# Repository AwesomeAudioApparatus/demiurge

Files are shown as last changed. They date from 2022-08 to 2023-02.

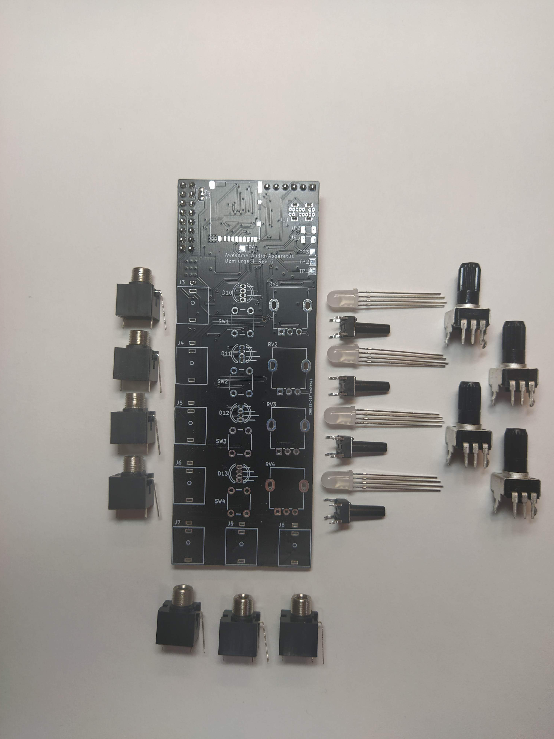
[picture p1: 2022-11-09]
photos/demiurge1-RevG-14.jpg

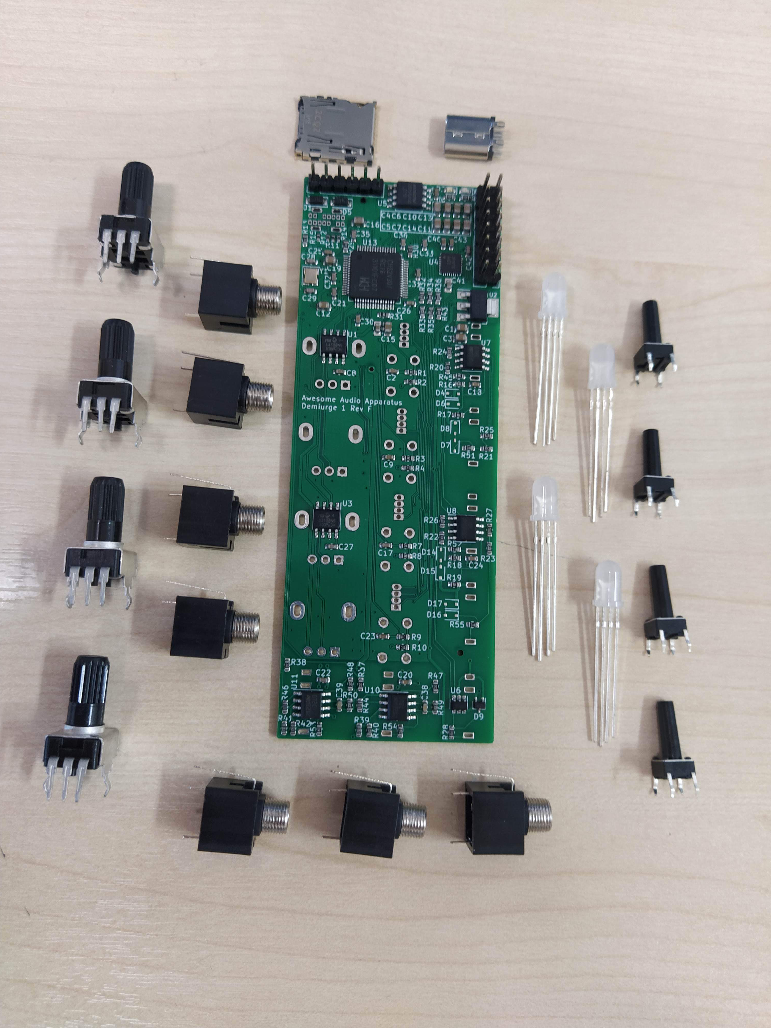
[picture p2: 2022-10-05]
photos/demiurge1-kit-2.jpg

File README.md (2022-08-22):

# Demiurge

Demiurge is a combination of Hardware and Software for Digital Sound Processing in the Eurorack Modular Synthesizer environment.

The "Demiurge 1" board is an 8 HP Eurorack compatible board, the functionality defined in software and custom front panel can either 
be made by hand, ordered from local mechanical shops or ordered from PCB manufacturers (KiCad template for front panel exists).

The "Demiurge Sound Processing Engine" is a system to more easily create Eurorack module functionality. A simple VCO module may look like this;

```C
#include "demiurge.h"
#include "demiurge-board.h"

static control_pair_t pair1;  // frequency
static control_pair_t pair2;  // amplitude

static control_pair_t pair3;  // frequency
static control_pair_t pair4;  // amplitude

static audio_outport_t out1;
static audio_outport_t out2;
static oscillator_t oscillator1;
static oscillator_t oscillator2;

/* Simple 2 VCO. SAW on output 1 and SQUARE on output 2. */

void vco_prepare() {
    demiurge_samplerate = 48000;      // 48000 samples/second
    demiurge_set_inport_cv(1);
    demiurge_set_inport_cv(2);
    demiurge_set_inport_cv(3);
    demiurge_set_inport_cv(4);

    demiurge_set_outport_audio(1);
    demiurge_set_outport_audio(2);
}

void vco_setup() {
    // Initialize the hardware configuration
    control_pair_init(&pair1, 1);     // FREQUENCY = CV+Pot at the top
    control_pair_init(&pair2, 2);     // AMPLITUDE = CV+Pot at the second position from the top
    control_pair_init(&pair3, 3);     // FREQUENCY = CV+Pot at the third position from top
    control_pair_init(&pair4, 4);     // AMPLITUDE = CV+Pot at the bottom
    audio_outport_init(&out1, 1);     // Audio Out on left output channel
    audio_outport_init(&out2, 2);     // Audio Out on right output channel

    // Initialize the oscillators
    oscillator_init(&oscillator1);
    oscillator_init(&oscillator2);

    // Set up the oscillators to SINE wave form

    oscillator_configure_mode(&oscillator1, SAW);
    oscillator_configure_mode(&oscillator2, SQUARE);

    oscillator_configure_frequency(&oscillator1, &pair1.me);
    oscillator_configure_frequency(&oscillator2, &pair3.me);

    oscillator_configure_amplitude(&oscillator1, &pair2.me);
    oscillator_configure_amplitude(&oscillator2, &pair4.me);

    // Connect Oscillator to outputs
    audio_outport_configure_input(&out1, &oscillator1.me);
    audio_outport_configure_input(&out2, &oscillator2.me);
}

void vco_loop() {
   // handle buttons and LEDs
}

int main(void)
{
    vco_prepare();                  // Prepare the board for the functionality

    demiurge_driver_init();         // Initialize the hardware driver
    demiurge_init();                // Initialize the Demiurge platform
    vco_setup();                    // Set up the functionality
    demiurge_start();               // Start the audio processing
    while(1)
    {
        vco_loop();                 // Give time for LEDs and Buttons
    }
}

```

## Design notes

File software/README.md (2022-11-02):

# Readme
This software is organized to be a Demiurge Sound Processing project, from
which the STM32PackCreator (../stm32-packs/demiurge1) will read the files to
package up the installable Software Pack in STM32CubeMX.

**NOTE 1**: This is intended as the development environment for the Installable 
packs, not to derive your own projects from.

**NOTE 2**: Only the build system and IDE setup of Jetbrains' CLion IDE will
be actively maintained. Any STM32CubeIDE files may or may not work; maintainers
are welcome.

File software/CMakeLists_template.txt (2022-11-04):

#${templateWarning}
set(CMAKE_SYSTEM_NAME Generic)
set(CMAKE_SYSTEM_VERSION 1)
${cmakeRequiredVersion}

if ("$${CMAKE_BUILD_TYPE}" STREQUAL "")
    set(CMAKE_BUILD_TYPE Debug)
endif()

# project settings
project(${projectName} C ASM)
set(CMAKE_C_STANDARD 11)

# specify cross-compilers and tools
set(CMAKE_C_COMPILER arm-none-eabi-gcc)
set(CMAKE_ASM_COMPILER arm-none-eabi-gcc)
set(CMAKE_AR arm-none-eabi-ar)
set(CMAKE_OBJCOPY arm-none-eabi-objcopy)
set(CMAKE_OBJDUMP arm-none-eabi-objdump)
set(SIZE arm-none-eabi-size)
set(CMAKE_TRY_COMPILE_TARGET_TYPE STATIC_LIBRARY)

add_compile_definitions(ARM_MATH_CM4;ARM_MATH_MATRIX_CHECK;ARM_MATH_ROUNDING)
add_compile_options(-mfloat-abi=hard -mfpu=fpv4-sp-d16)
add_link_options(-mfloat-abi=hard -mfpu=fpv4-sp-d16)

add_compile_options(-mcpu=${mcpu} -mthumb -mthumb-interwork)
add_compile_options(-ffunction-sections -fdata-sections -fno-common -fmessage-length=0)

# Enable assembler files preprocessing
add_compile_options($<$<COMPILE_LANGUAGE:ASM>:-x$<SEMICOLON>assembler-with-cpp>)

add_definitions(-DSTM32F446xx -DUSE_HAL_DRIVER -DARM_MATH_CM4 -DDEBUG)

set(LINKER_SCRIPT ${CMAKE_SOURCE_DIR}/STM32F446RETX_FLASH.ld)

add_link_options(-mcpu=cortex-m4 -mthumb -mthumb-interwork)
add_link_options(-Wl,-gc-sections,--print-memory-usage,-Map=${PROJECT_BINARY_DIR}/${PROJECT_NAME}-stm32f446.map)
add_link_options(-T ${LINKER_SCRIPT})

if ("$${CMAKE_BUILD_TYPE}" STREQUAL "Release")
    message(STATUS "Maximum optimization for speed")
    add_compile_options(-Ofast)
elseif ("$${CMAKE_BUILD_TYPE}" STREQUAL "RelWithDebInfo")
    message(STATUS "Maximum optimization for speed, debug info included")
    add_compile_options(-Ofast -g)
elseif ("$${CMAKE_BUILD_TYPE}" STREQUAL "MinSizeRel")
    message(STATUS "Maximum optimization for size")
    add_compile_options(-Os)
else ()
    message(STATUS "Minimal optimization, debug info included")
    add_compile_options(-Og -g)
endif ()

include_directories(${includes})

include_directories(
        Drivers/BSP/AwesomeAudioApparatus_board/Demiurge1
        Middlewares/ThirdParty/AwesomeAudioApparatus_Audio/Demiurge/inc
        User/
        Middlewares/ST/ARM/DSP/Inc
)

add_definitions(${defines})

file(GLOB_RECURSE SOURCES ${sources} "Middlewares/*.*" "User/App/*.*" "Drivers/*.*")

set(LINKER_SCRIPT $${CMAKE_SOURCE_DIR}/${linkerScript})

add_link_options(-Wl,-gc-sections,--print-memory-usage,-Map=$${PROJECT_BINARY_DIR}/$${PROJECT_NAME}.map)
add_link_options(-mcpu=${mcpu} -mthumb -mthumb-interwork)
add_link_options(-T $${LINKER_SCRIPT})

link_libraries(m)
add_executable($${PROJECT_NAME}.elf $${SOURCES} $${LINKER_SCRIPT})
target_link_libraries(${PROJECT_NAME}.elf ${CMAKE_SOURCE_DIR}/Middlewares/ST/ARM/DSP/Lib/libarm_cortexM4l_math.a)

set(HEX_FILE $${PROJECT_BINARY_DIR}/$${PROJECT_NAME}.hex)
set(BIN_FILE $${PROJECT_BINARY_DIR}/$${PROJECT_NAME}.bin)

add_custom_command(TARGET $${PROJECT_NAME}.elf POST_BUILD
        COMMAND $${CMAKE_OBJCOPY} -Oihex $<TARGET_FILE:$${PROJECT_NAME}.elf> $${HEX_FILE}
        COMMAND $${CMAKE_OBJCOPY} -Obinary $<TARGET_FILE:$${PROJECT_NAME}.elf> $${BIN_FILE}
        COMMENT "Building $${HEX_FILE}
Building $${BIN_FILE}")

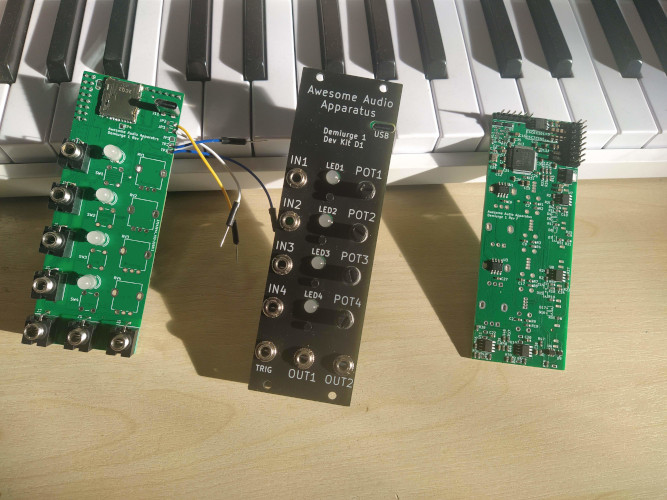
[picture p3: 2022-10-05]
photos/opencart/demiurge1-RevF-8-opencart.jpg

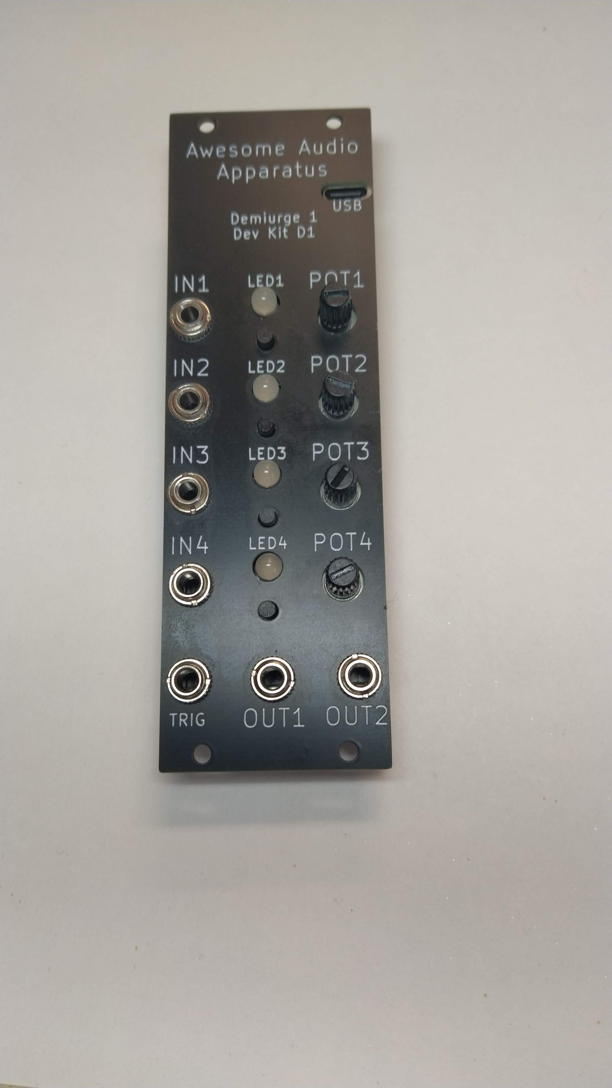
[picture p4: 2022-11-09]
photos/demiurge1-RevG-10.jpg

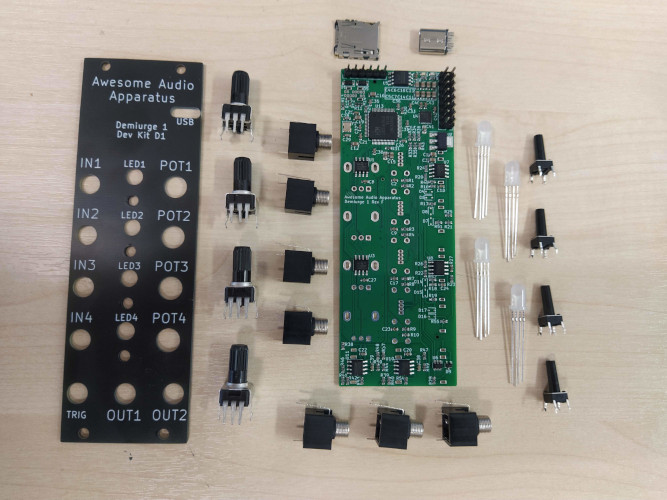
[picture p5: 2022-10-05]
photos/opencart/demiurge1-kit-1-opencart.jpg

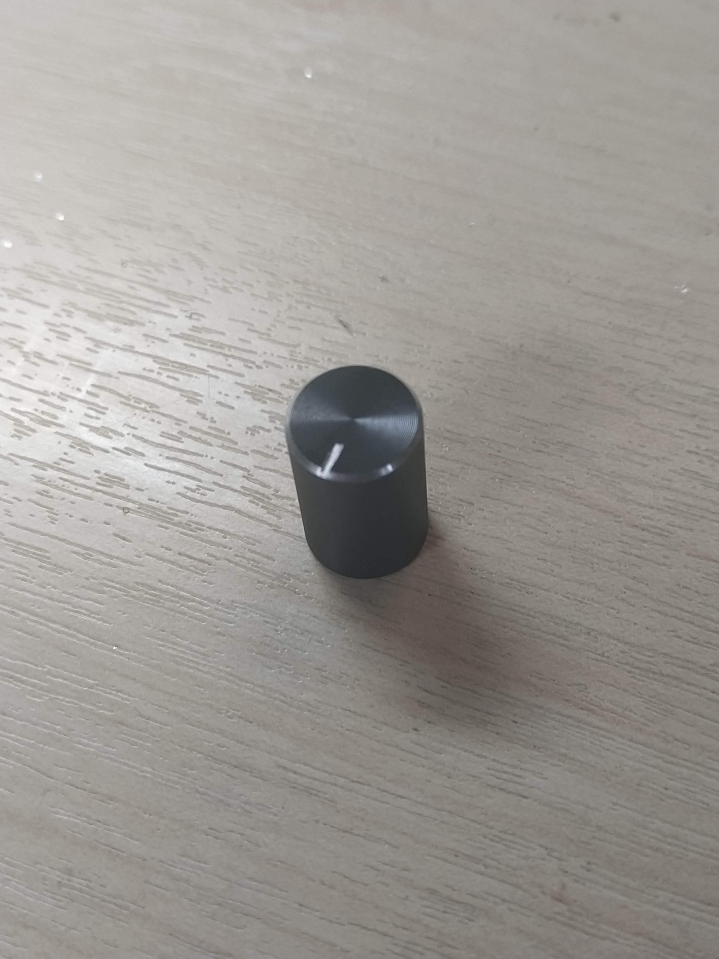
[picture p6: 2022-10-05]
photos/knob-4.jpg

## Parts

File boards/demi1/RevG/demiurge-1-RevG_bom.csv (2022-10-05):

Comment | Designator | Footprint | LCSC
22uF | C1,C3,C4,C5,C6,C7,C10,C11,C12,C13,C14,C15,C16,C19 | Capacitor_SMD:C_0805_2012Metric | C129303
100nF | C2,C8,C9,C17,C18,C20,C21,C22,C23,C24,C25,C26,C27,C30,C31,C32,C33,C34,C35,C36,C42,C43 | Capacitor_SMD:C_0603_1608Metric | C14663
20pF | C28,C29 | Capacitor_SMD:C_0603_1608Metric | C1648
4.7uF | C37,C41 | Capacitor_SMD:C_0805_2012Metric | C19666
1nF | C38,C39 | Capacitor_SMD:C_0603_1608Metric | C1588
1uF | C40 | Capacitor_SMD:C_0603_1608Metric | C15849
~ | D1,D5 | Diode_SMD:D_SOD-123 | C8598
~ | D10,D11,D12,D13 | LED_THT:LED_D5.0mm-4_RGB | C331057
Red | D2 | LED_SMD:LED_0603_1608Metric | C2286
Green | D3 | LED_SMD:LED_0603_1608Metric | C72043
10V | D4,D6,D7,D8,D14,D15,D16,D17 | Diode_SMD:D_SOD-323 | C493185
BAT54SW | D9 | Package_TO_SOT_SMD:SOT-323_SC-70 | C78260
~ | J1 | Connector_PinHeader_2.54mm:PinHeader_2x08_P2.54mm_Vertical | C68234
~ | J11 | aaa:USB_C_Receptacle_Vertical | C167321
Micro_SD_Card_Det_Hirose_DM3AT | J12 | Connector_Card:microSD_HC_Hirose_DM3AT-SF-PEJM5 | C114218
Conn_01x06 | J2 | Connector_PinHeader_2.54mm:PinHeader_1x06_P2.54mm_Vertical | C37208
~ | J3,J4,J5,J6,J7,J8,J9 | aaa:PJ301M-12
~ | JP1 | Jumper:SolderJumper-3_P1.3mm_Bridged12_RoundedPad1.0x1.5mm
~ | JP2,JP3 | Capacitor_SMD:C_1206_3216Metric
10k | R1,R2,R3,R4,R7,R8,R9,R10,R13,R29,R37,R38,R47,R48 | Resistor_SMD:R_0603_1608Metric | C25804
22R | R11,R12 | Resistor_SMD:R_0402_1005Metric | C25092
5.1k | R14,R15 | Resistor_SMD:R_0402_1005Metric | C25905
18k | R16,R18 | Resistor_SMD:R_0603_1608Metric | C25810
13k | R17,R19 | Resistor_SMD:R_0603_1608Metric | C22797
20k | R20,R21,R22,R23,R49,R50 | Resistor_SMD:R_0603_1608Metric | C4184
3k3 | R24,R25,R26,R27,R56,R57 | Resistor_SMD:R_0603_1608Metric | C22978
1k | R28 | Resistor_SMD:R_0603_1608Metric | C21190
0R | R30,R31 | Capacitor_SMD:C_0603_1608Metric | C21189
51R | R32,R35 | Resistor_SMD:R_0603_1608Metric | C23197
20R | R33,R34,R36,R43 | Resistor_SMD:R_0603_1608Metric | C22950
36k | R39,R41 | Resistor_SMD:R_0603_1608Metric | C23147
22k | R40,R42 | Resistor_SMD:R_0603_1608Metric | C31850
33k | R44,R46 | Resistor_SMD:R_0603_1608Metric | C4216
100 | R45,R51,R52,R53,R54,R55 | Resistor_SMD:R_0603_1608Metric | C22775
2k | R5,R6 | Resistor_SMD:R_0603_1608Metric | C22975
~ | RV1,RV2,RV3,RV4 | aaa:Potentiometer_Alpha_RD901F-40-00D_Single_Vertical
~ | SW1,SW2,SW3,SW4 | Button_Switch_THT:SW_PUSH_6mm_H8mm
TP1 | TP1 | TestPoint:TestPoint_Pad_1.5x1.5mm
TP2 | TP2 | TestPoint:TestPoint_Pad_1.5x1.5mm
SWO | TP3,TP4 | TestPoint:TestPoint_Pad_1.5x1.5mm
MCP6002 | U1,U3 | Package_SO:SOIC-8_3.9x4.9mm_P1.27mm | C7377
STM32F446 | U13 | Package_QFP:LQFP-64_10x10mm_P0.5mm | C69336
AMS1117-3.3 | U2 | Package_TO_SOT_SMD:SOT-223-3_TabPin2 | C6186
AW20036 | U4 | Package_DFN_QFN:QFN-32-1EP_4x4mm_P0.4mm_EP2.65x2.65mm_ThermalVias | C401019
W25Q128JVS | U5 | Package_SO:SOIC-8_5.23x5.23mm_P1.27mm | C97521
74LVC1T45W6 | U6 | Package_TO_SOT_SMD:SOT-23-6 | C7843
TL072 | U7,U8,U10,U11 | Package_SO:SOIC-8_3.9x4.9mm_P1.27mm | C6961
16MHz | Y1 | Crystal:Crystal_SMD_3225-4Pin_3.2x2.5mm | C13738

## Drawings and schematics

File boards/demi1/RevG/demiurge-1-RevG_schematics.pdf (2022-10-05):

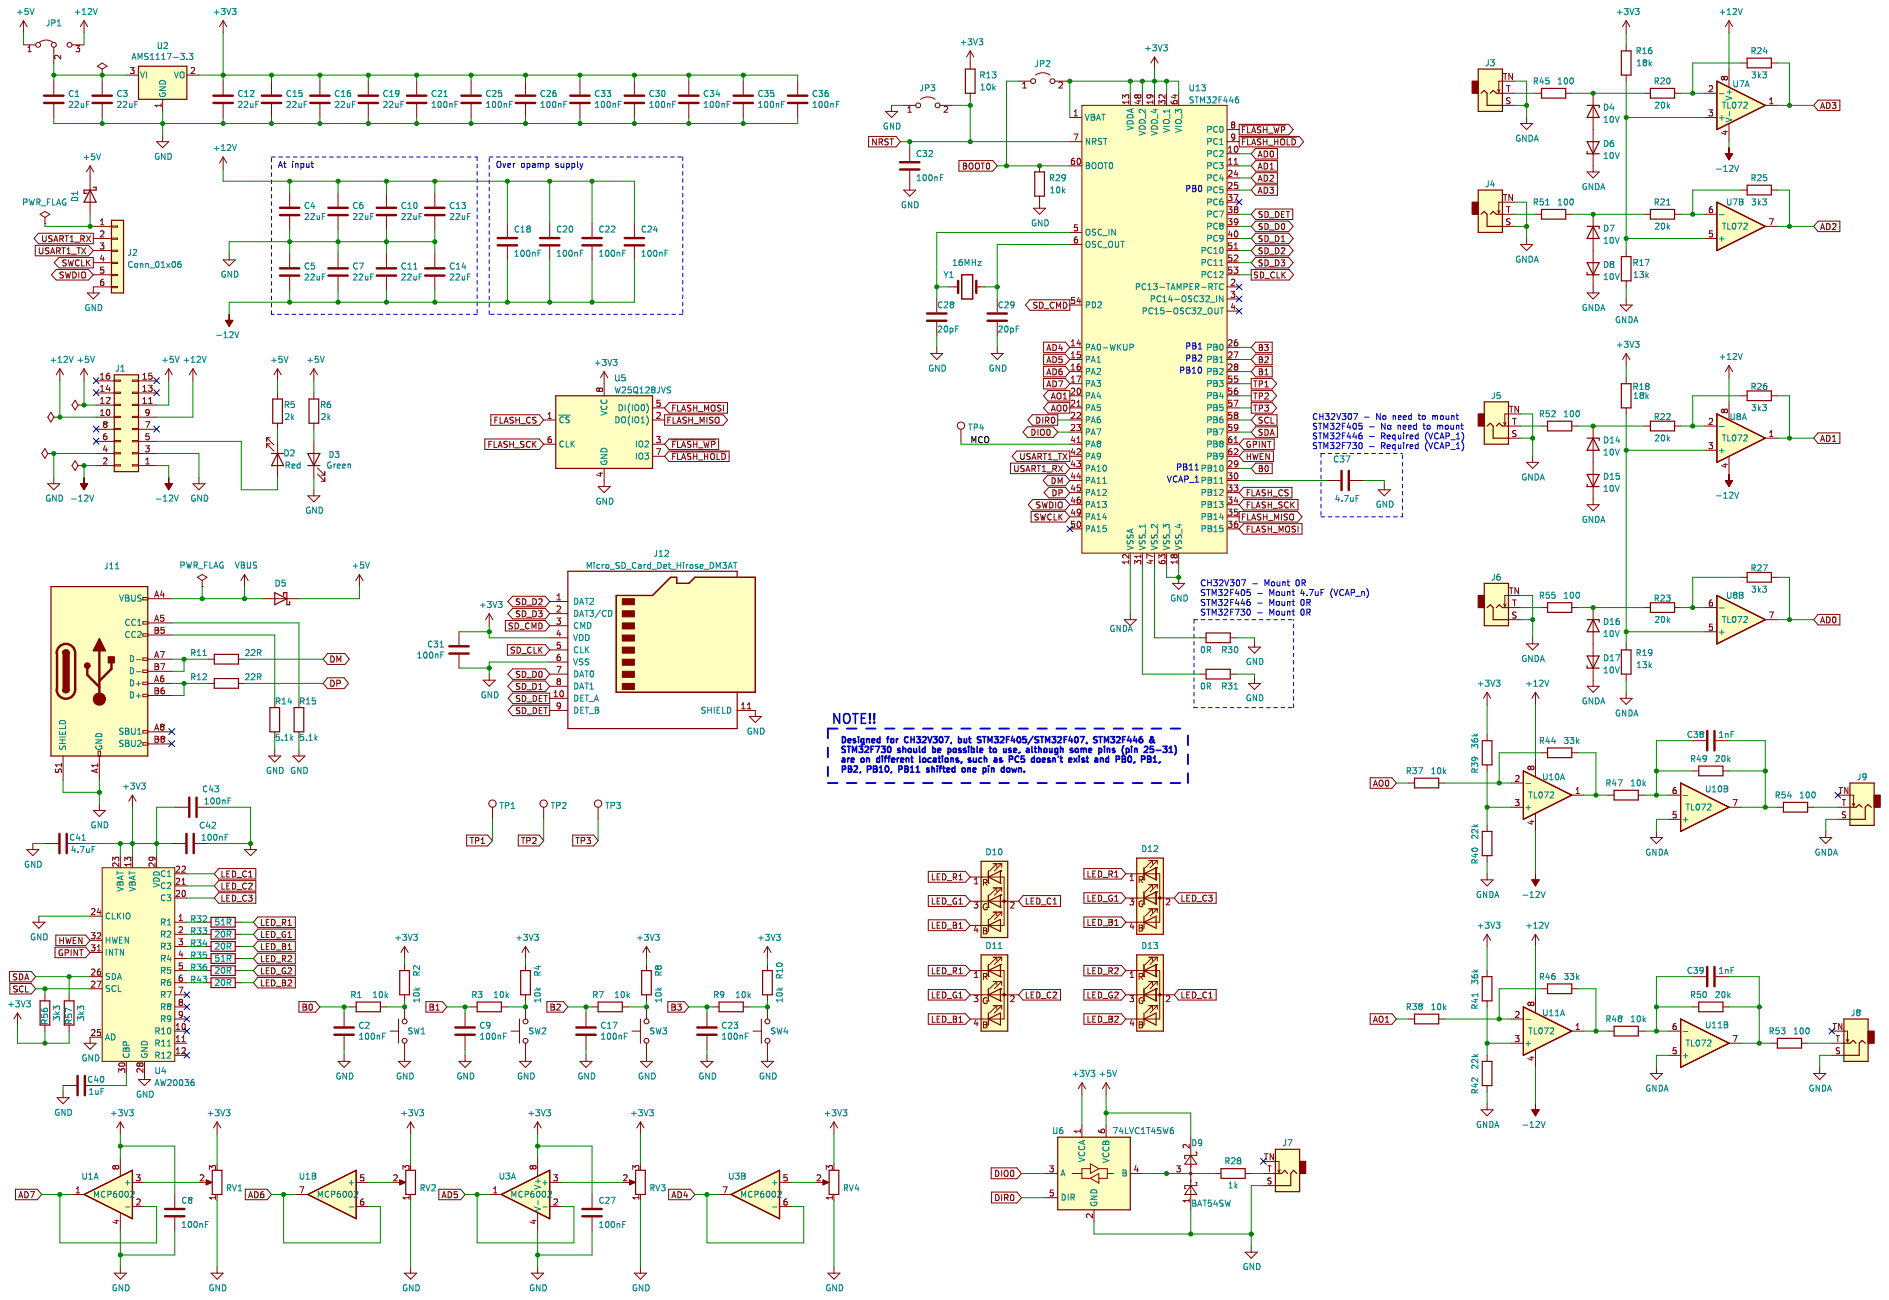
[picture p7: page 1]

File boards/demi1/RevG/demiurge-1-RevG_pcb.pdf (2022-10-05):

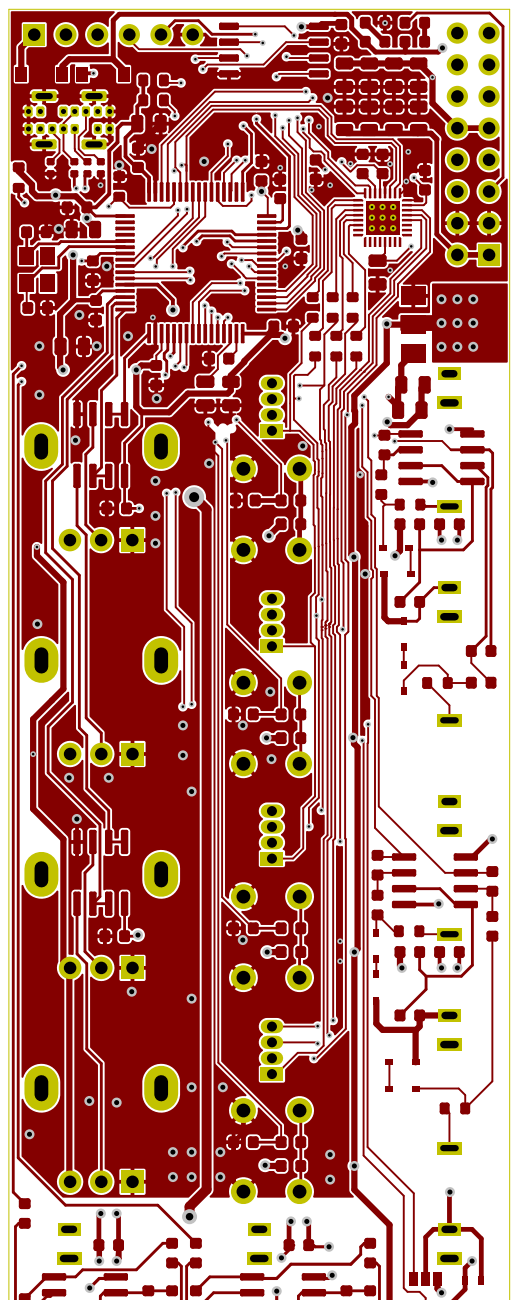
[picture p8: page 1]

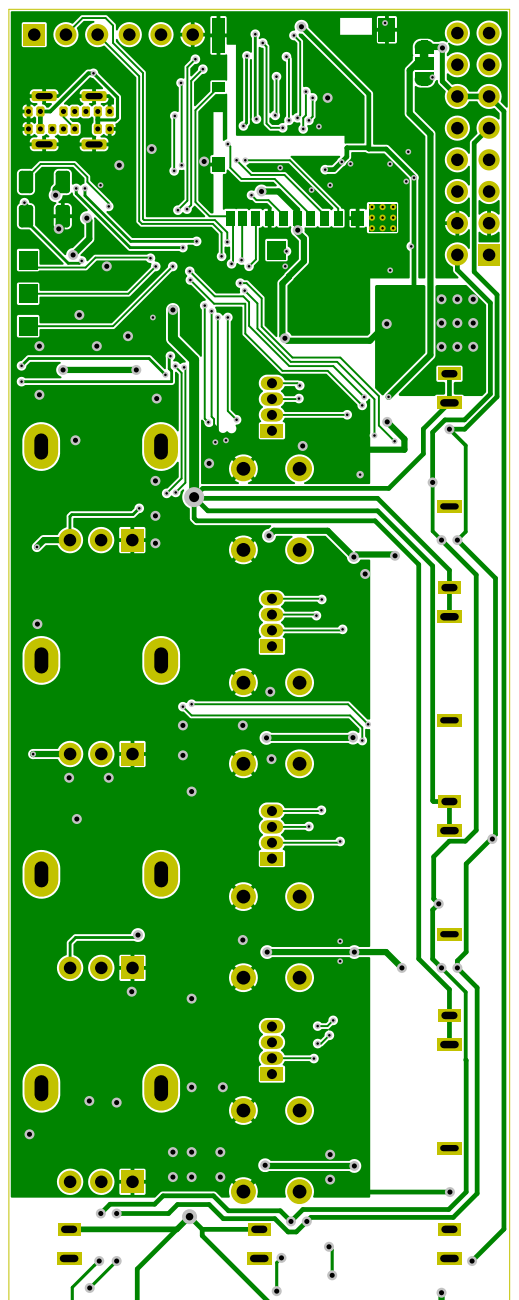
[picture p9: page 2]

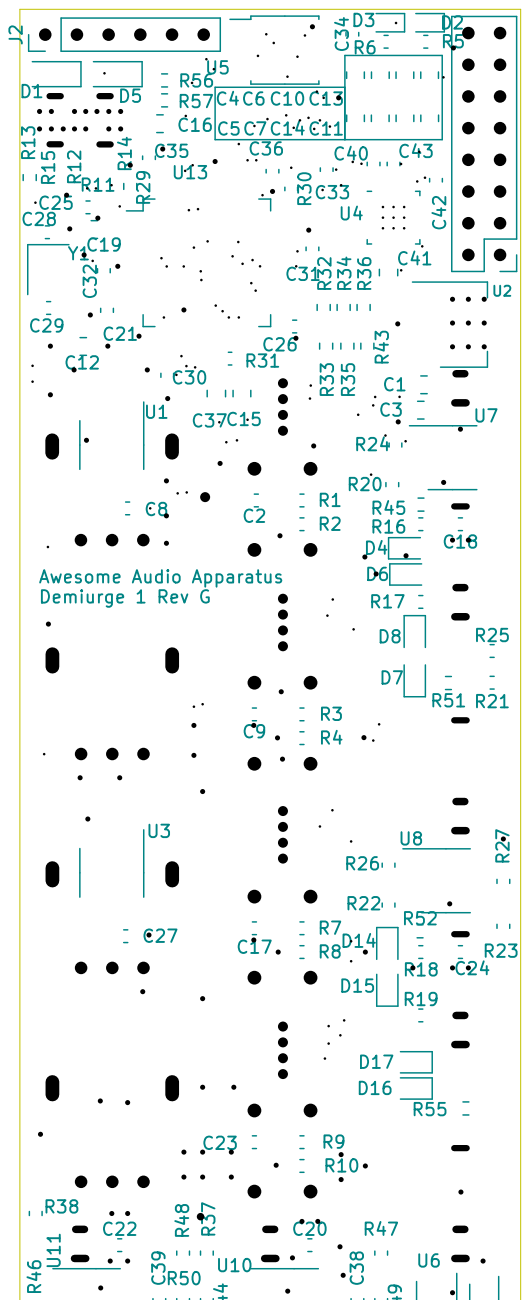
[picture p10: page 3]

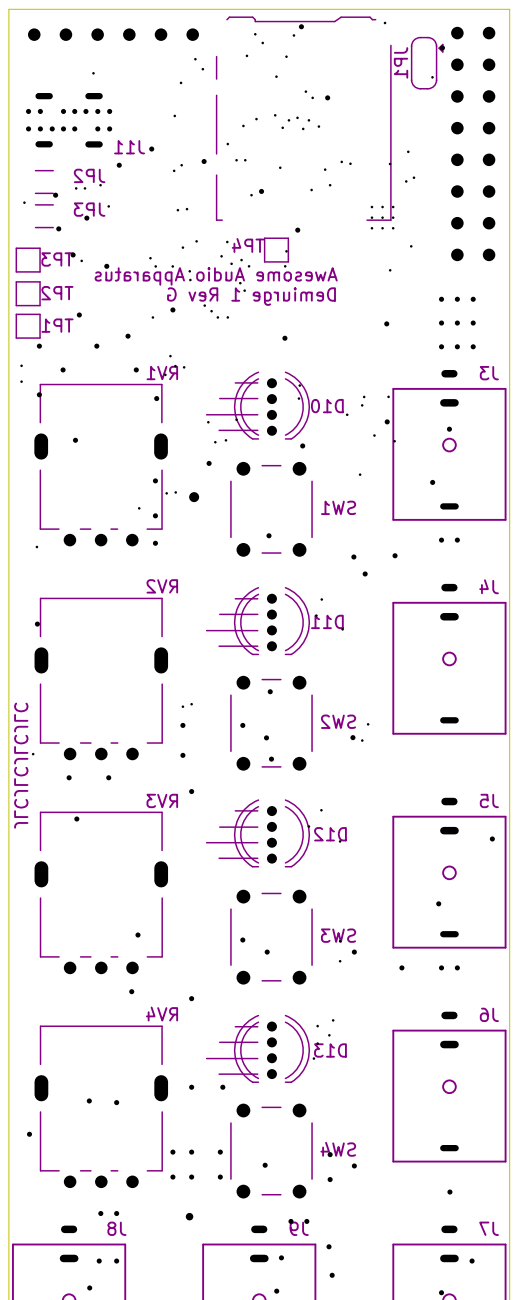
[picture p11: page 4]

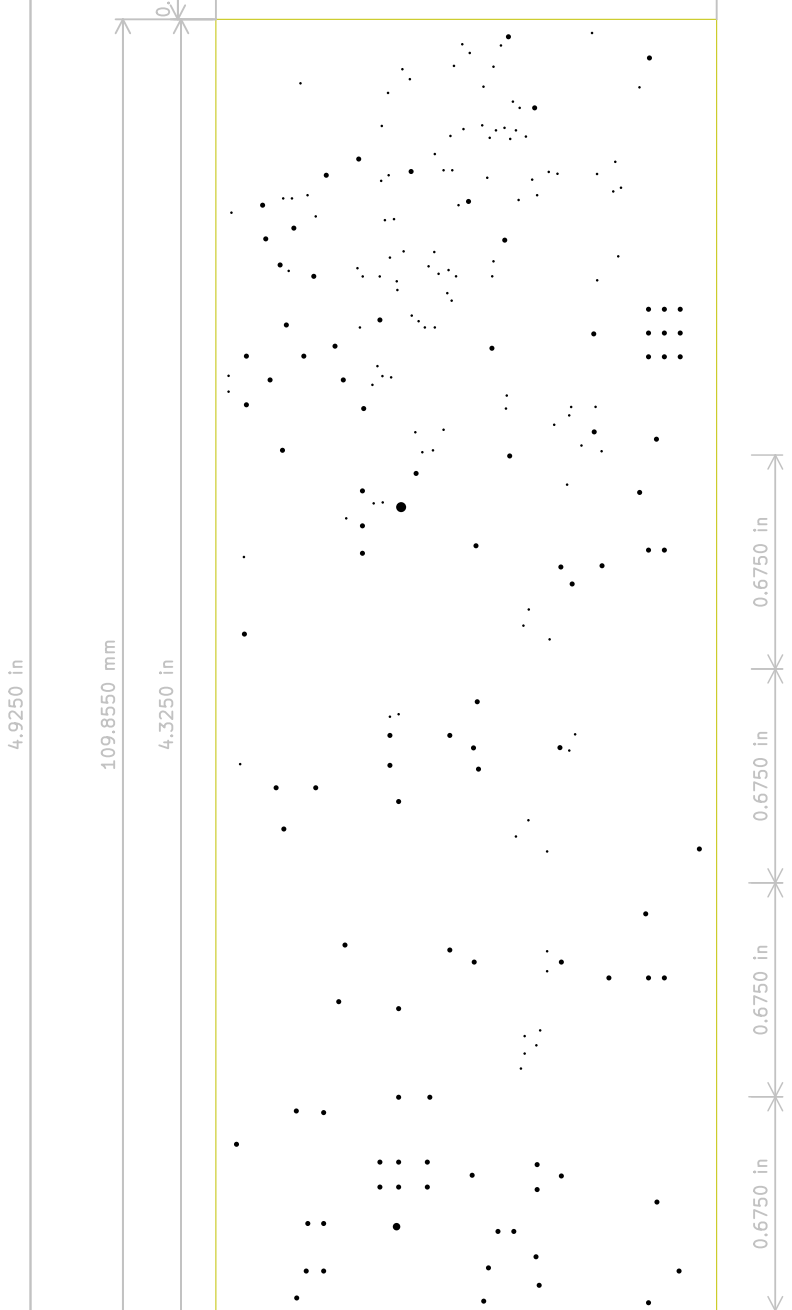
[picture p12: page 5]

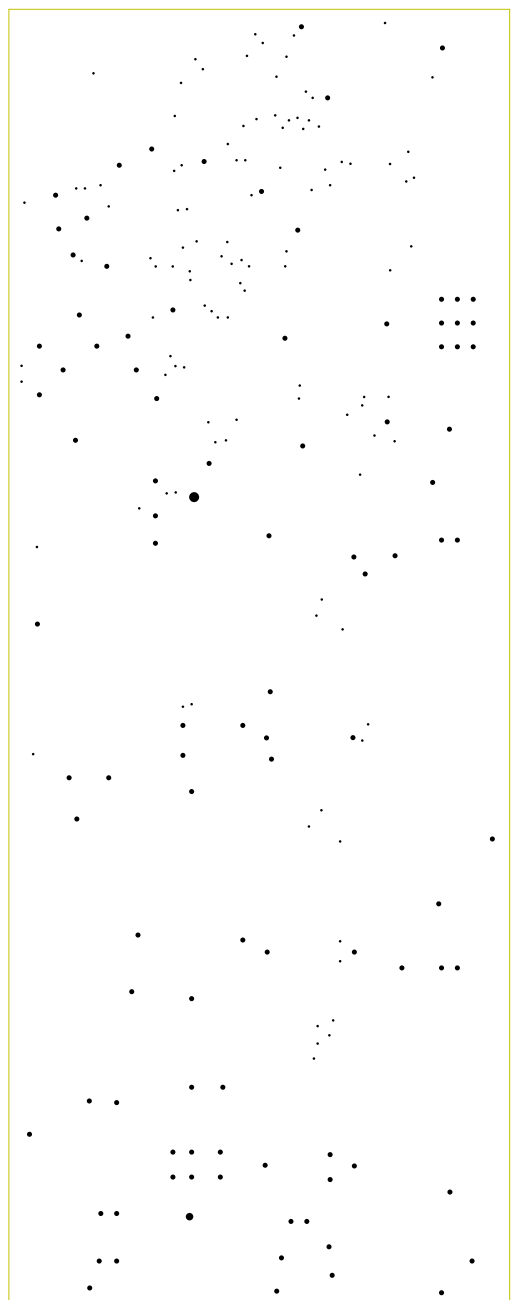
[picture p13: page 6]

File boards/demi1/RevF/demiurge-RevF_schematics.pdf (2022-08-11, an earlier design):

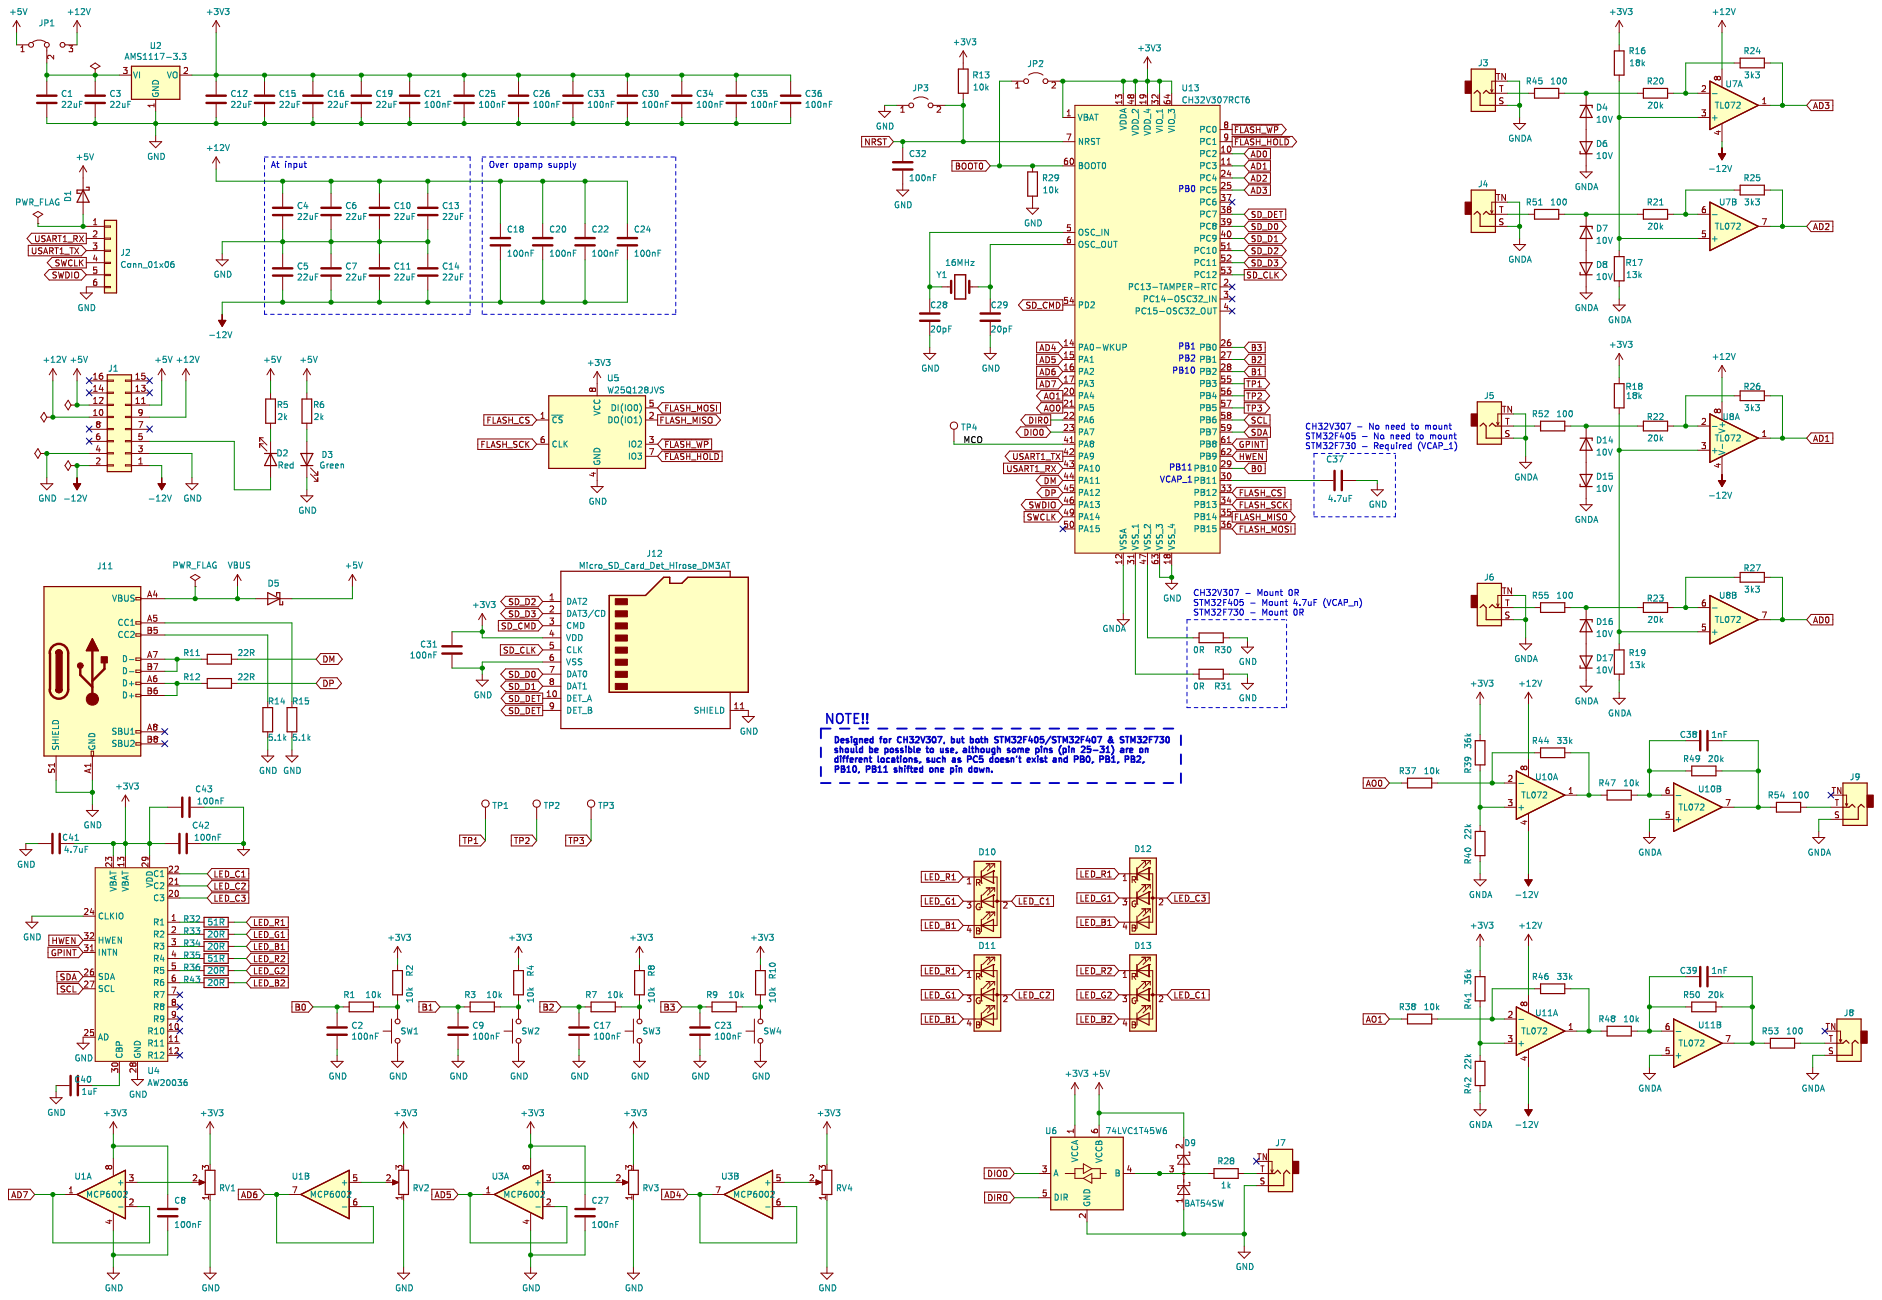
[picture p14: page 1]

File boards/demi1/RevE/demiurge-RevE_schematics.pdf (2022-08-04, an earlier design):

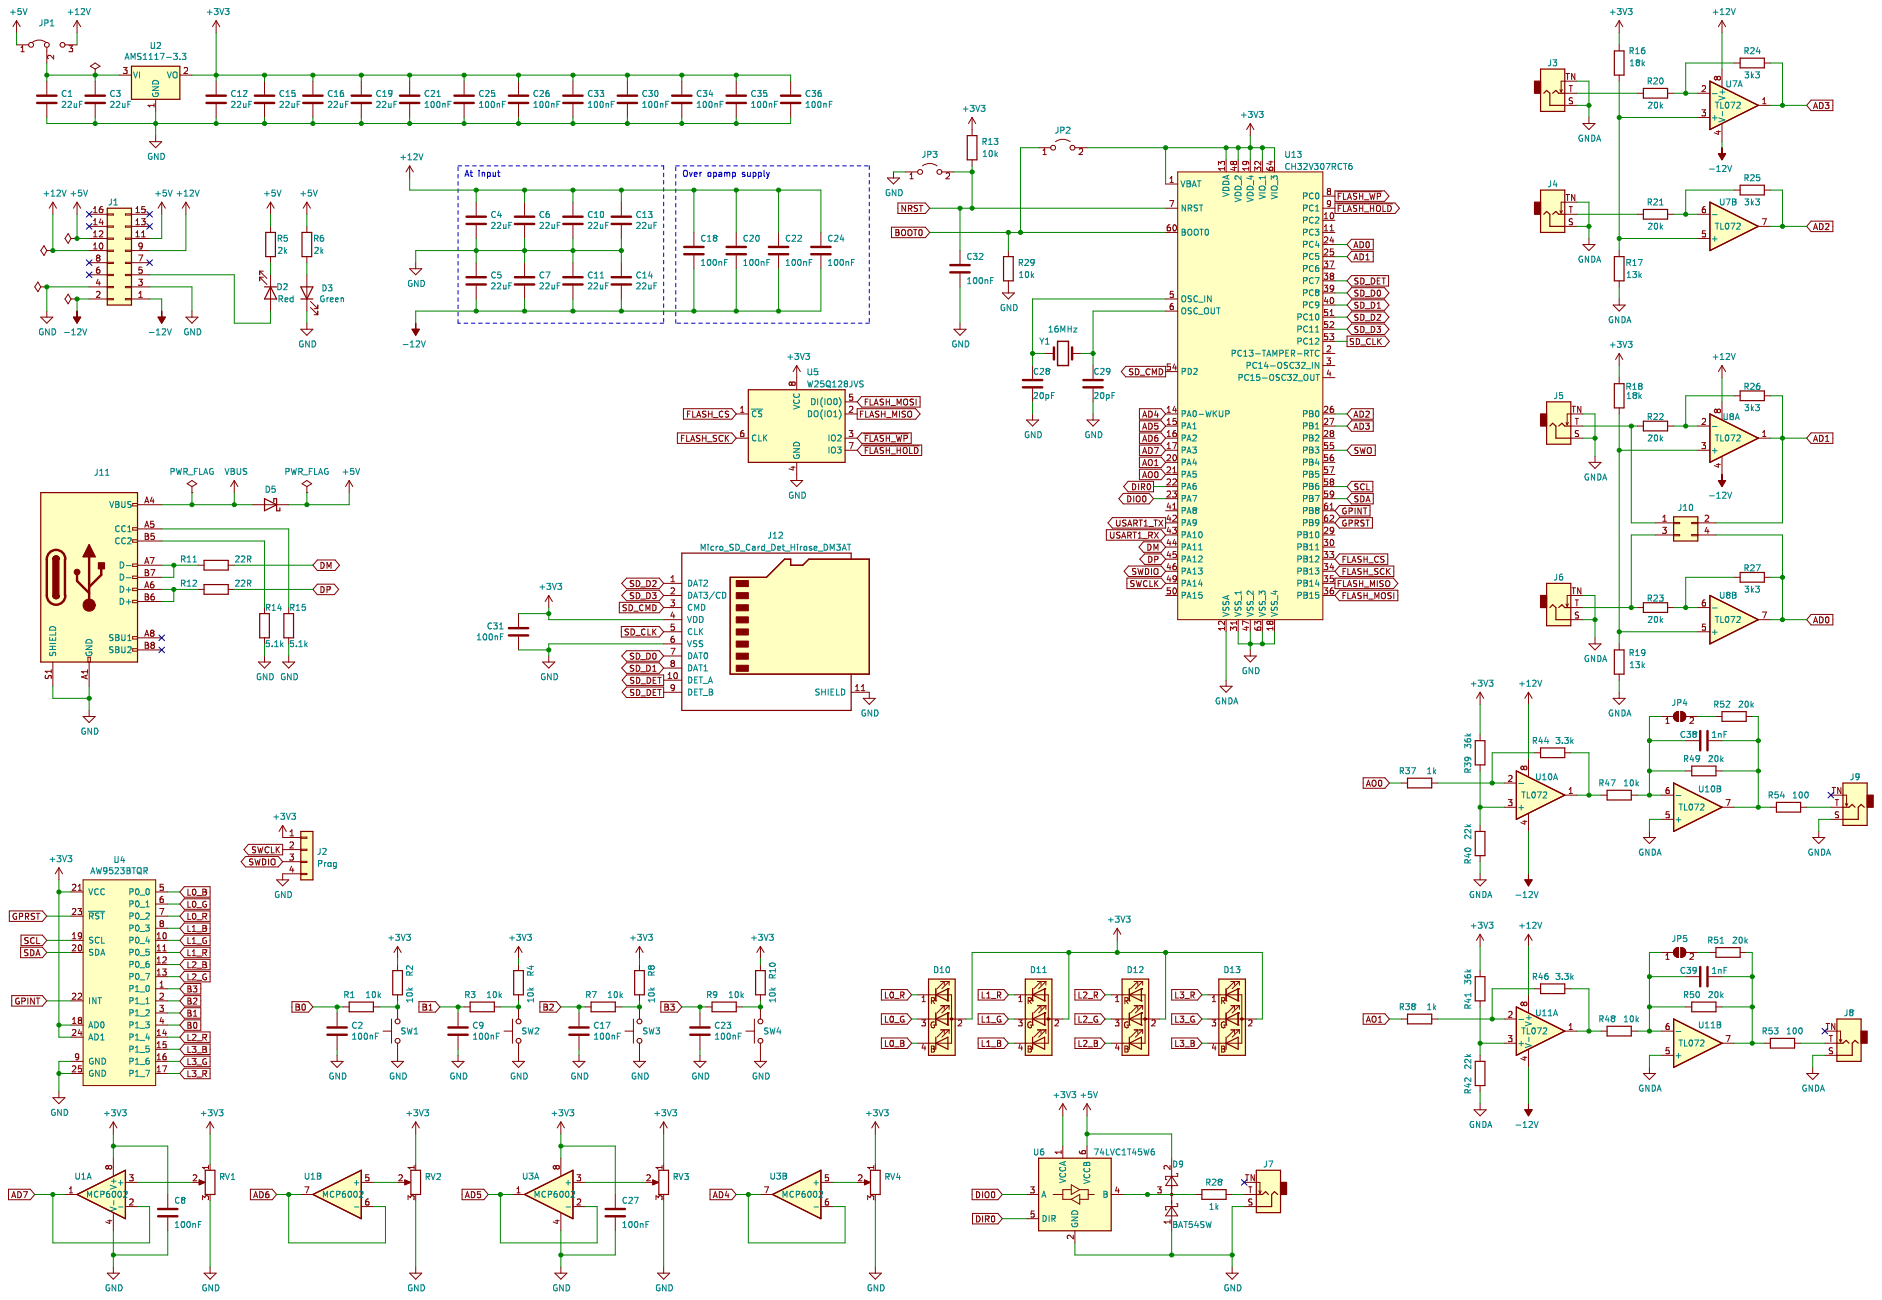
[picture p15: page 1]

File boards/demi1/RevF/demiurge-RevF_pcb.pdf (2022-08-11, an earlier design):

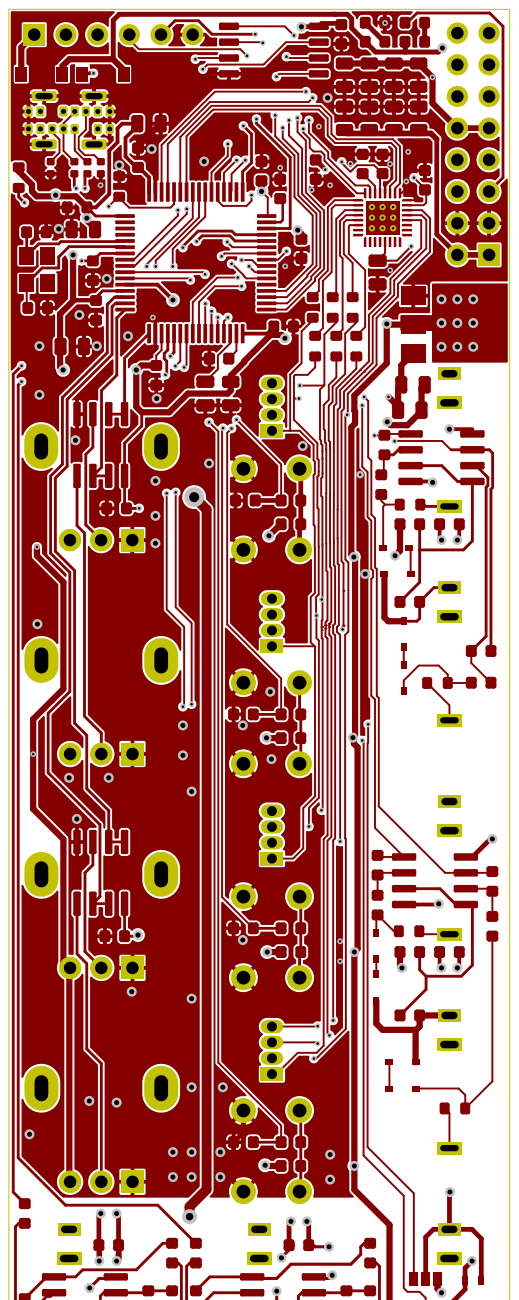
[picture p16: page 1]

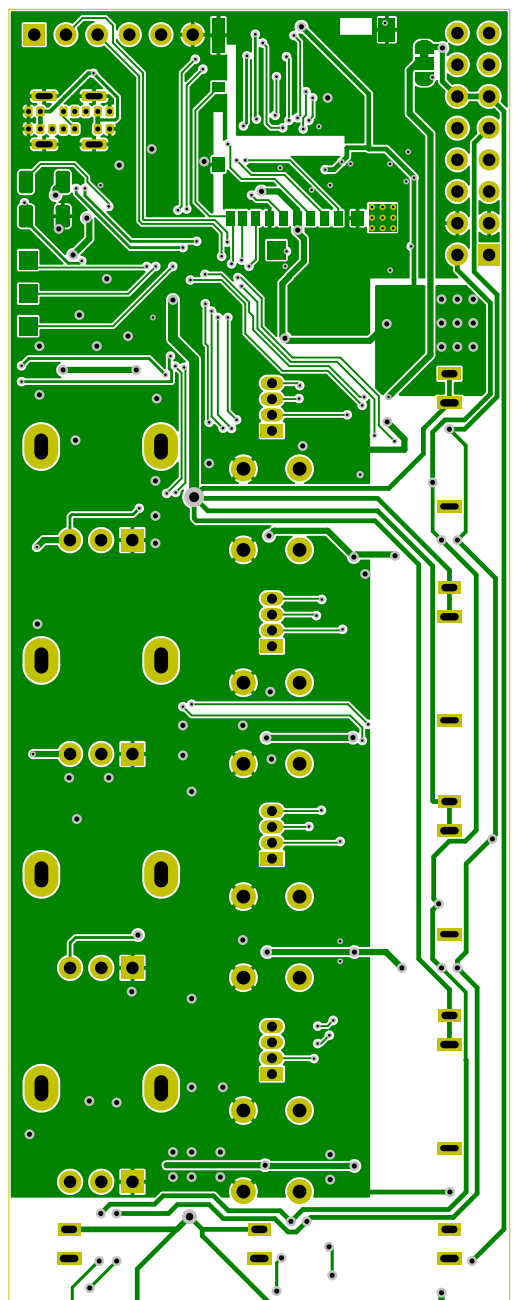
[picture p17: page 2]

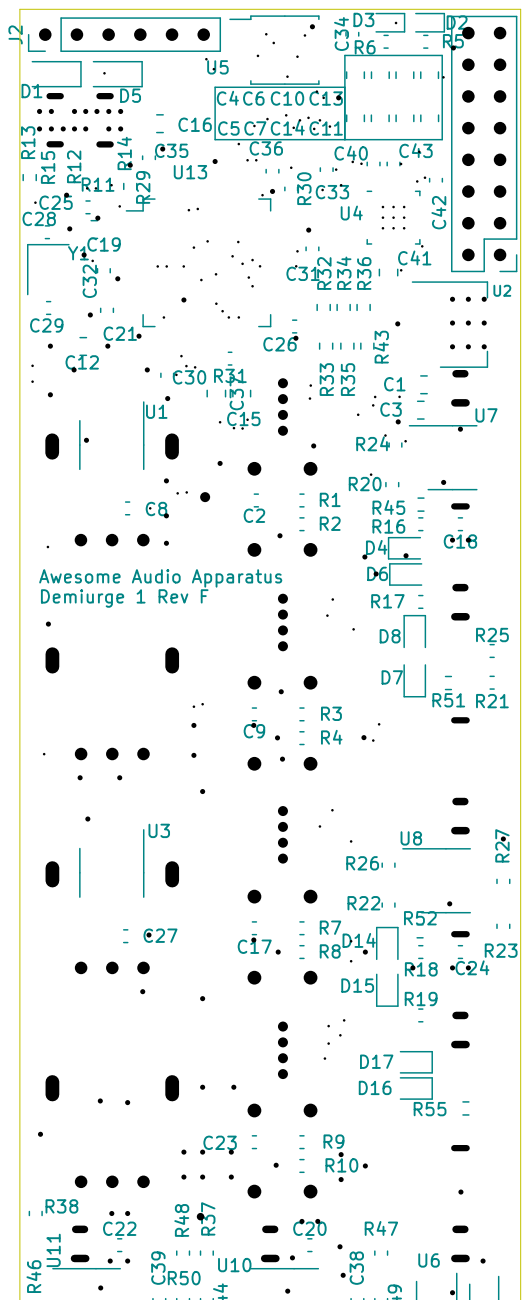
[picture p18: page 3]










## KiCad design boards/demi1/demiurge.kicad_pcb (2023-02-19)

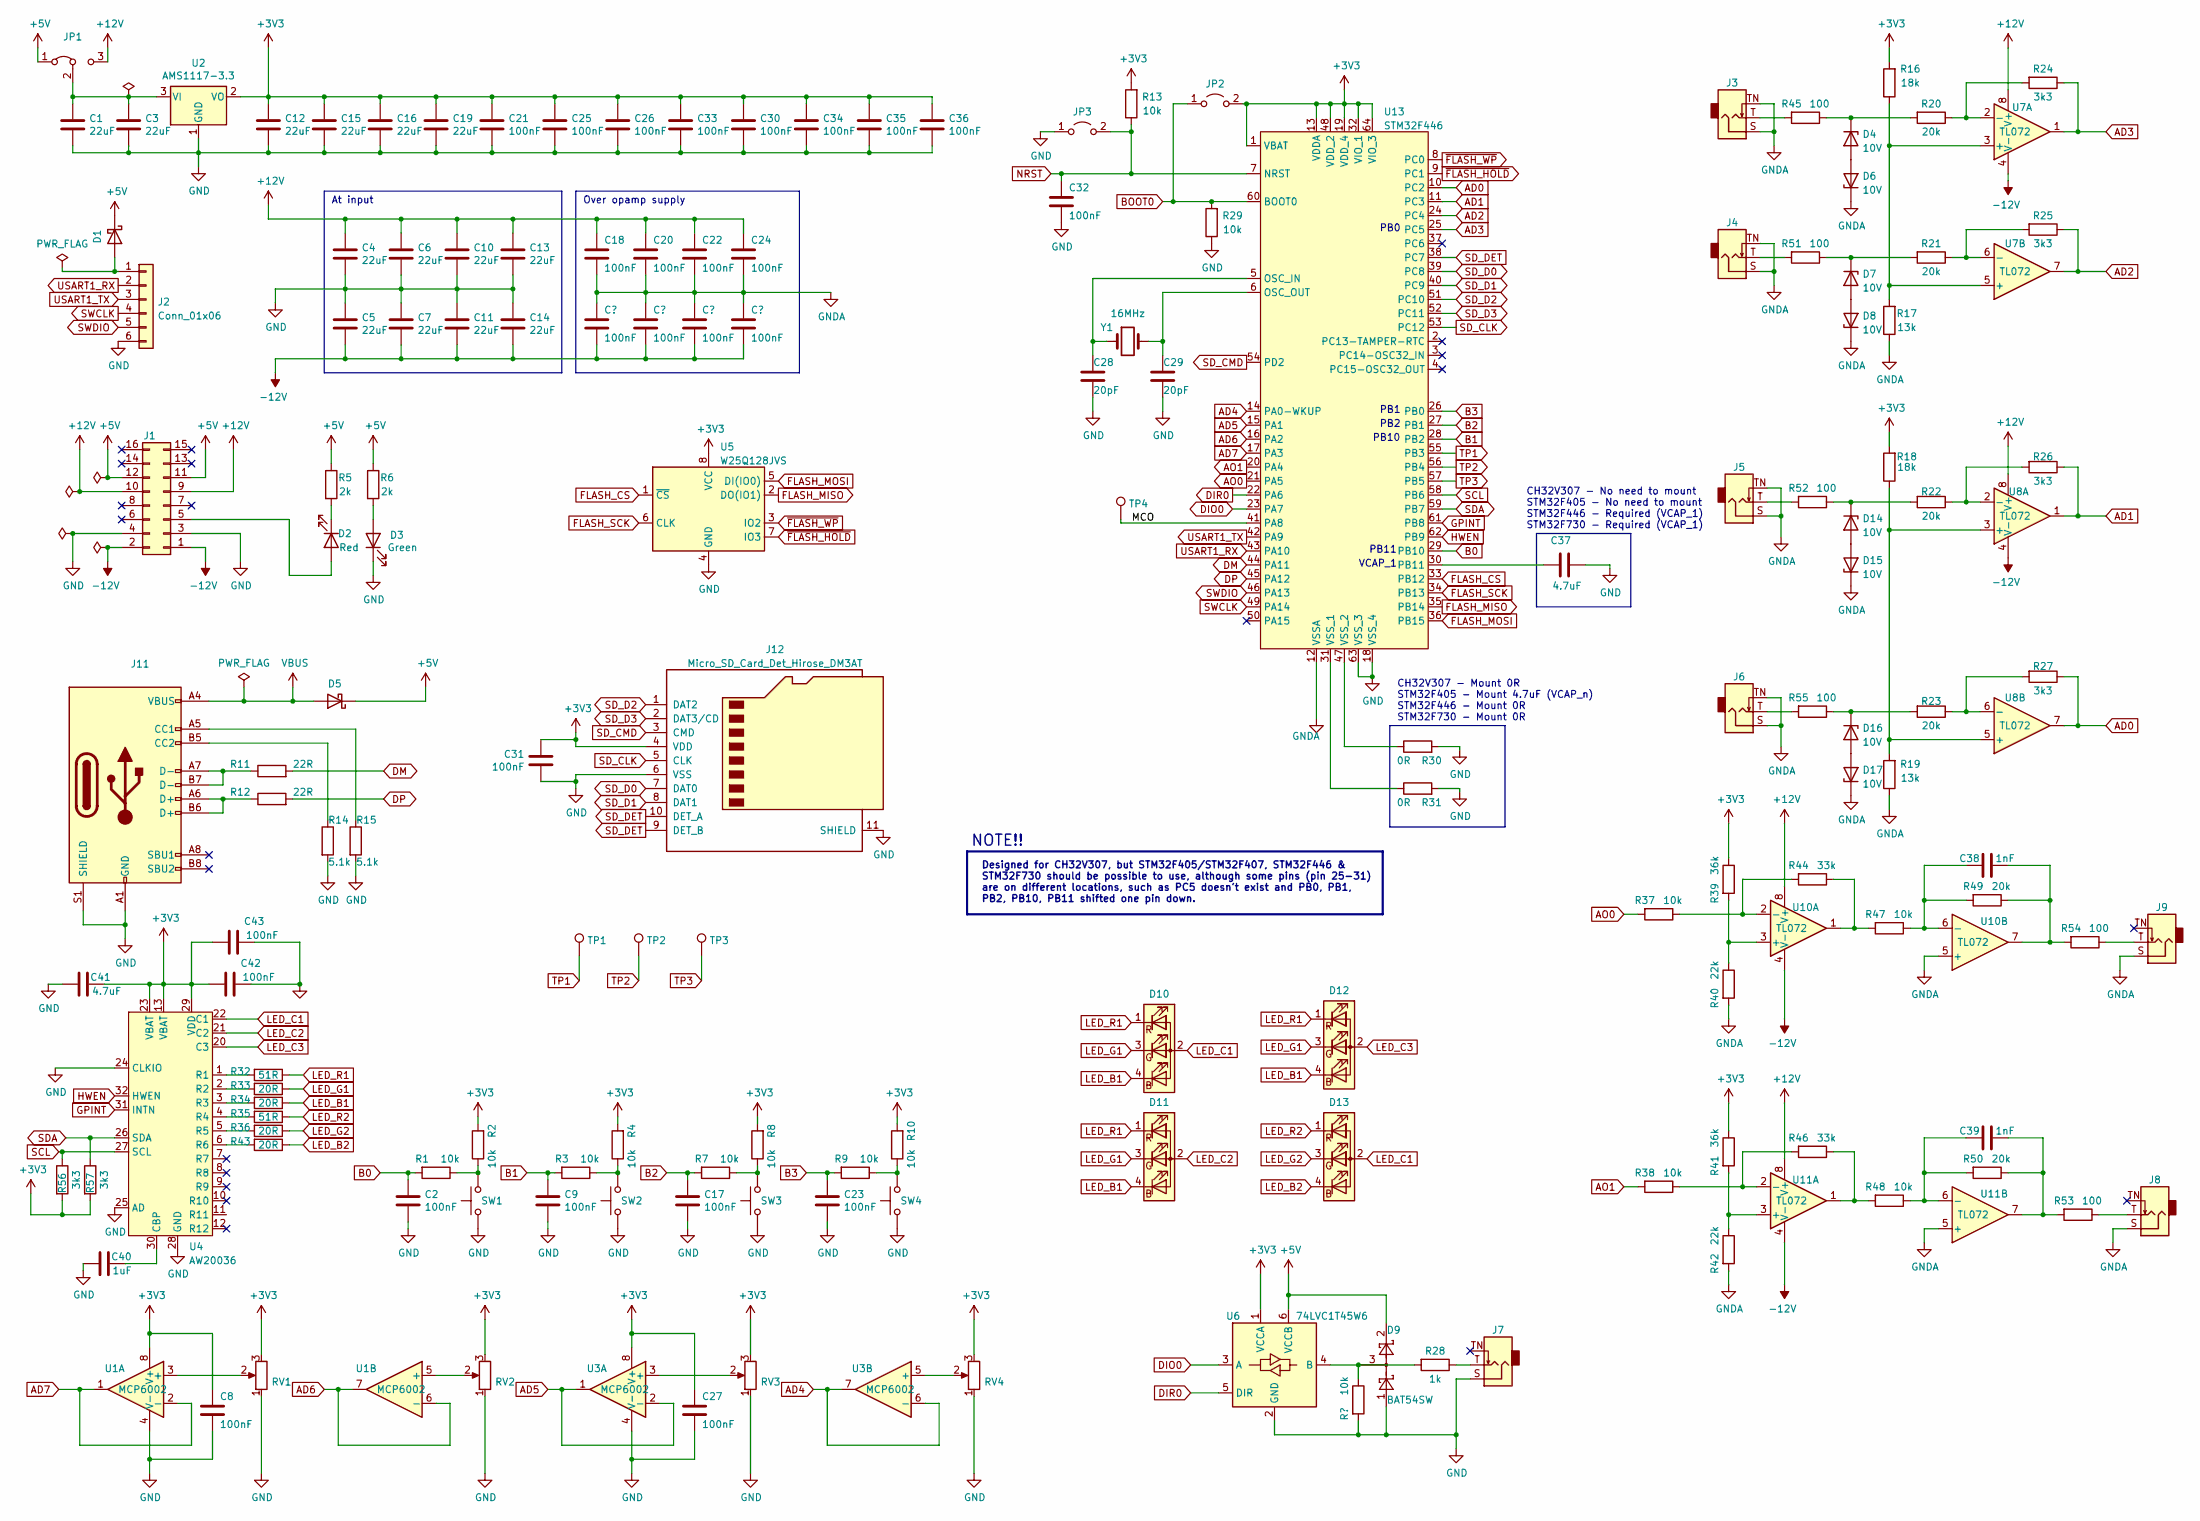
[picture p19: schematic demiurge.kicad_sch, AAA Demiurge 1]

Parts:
C1, C3, C4, C5, C6, C7, C10, C11, C12, C13, C14, C15, C16, C19: 22uF; C_0805_2012Metric; LCSC C129303
C2, C8, C9, C17, C18, C20, C21, C22, C23, C24, C25, C26, C27, C30, C31, C32, C33, C34, C35, C36, C42, C43: 100nF; C_0603_1608Metric; LCSC C14663
C28, C29: 20pF; C_0603_1608Metric; LCSC C1648
C37, C41: 4.7uF; C_0805_2012Metric; LCSC C19666
C38, C39: 1nF; C_0603_1608Metric; LCSC C1588
C40: 1uF; C_0603_1608Metric; LCSC C15849
D1, D5: D_SOD-123; LCSC C8598
D2: Red; LED_0603_1608Metric; LCSC C2286
D3: Green; LED_0603_1608Metric; LCSC C72043
D4, D6, D7, D8, D14, D15, D16, D17: 10V; D_SOD-323; LCSC C493185
D9: BAT54SW; SOT-323_SC-70; LCSC C78260
D10, D11, D12, D13: LED_D5.0mm-4_RGB; LCSC C331057
J1: PinHeader_2x08_P2.54mm_Vertical; LCSC C68234
J2: Conn_01x06; PinHeader_1x06_P2.54mm_Vertical; LCSC C37208
J3, J4, J5, J6, J7, J8, J9: PJ301M-12
J11: USB_C_Receptacle_Vertical; LCSC C167321
J12: Micro_SD_Card_Det_Hirose_DM3AT; microSD_HC_Hirose_DM3AT-SF-PEJM5; LCSC C114218
JP1: SolderJumper-3_P1.3mm_Bridged12_RoundedPad1.0x1.5mm
JP2, JP3: C_1206_3216Metric
R1, R2, R3, R4, R7, R8, R9, R10, R13, R29, R37, R38, R47, R48: 10k; R_0603_1608Metric; LCSC C25804
R5, R6: 2k; R_0603_1608Metric; LCSC C22975
R11, R12: 22R; R_0402_1005Metric; LCSC C25092
R14, R15: 5.1k; R_0402_1005Metric; LCSC C25905
R16, R18: 18k; R_0603_1608Metric; LCSC C25810
R17, R19: 13k; R_0603_1608Metric; LCSC C22797
R20, R21, R22, R23, R49, R50: 20k; R_0603_1608Metric; LCSC C4184
R24, R25, R26, R27, R56, R57: 3k3; R_0603_1608Metric; LCSC C22978
R28: 1k; R_0603_1608Metric; LCSC C21190
R30, R31: 0R; C_0603_1608Metric; LCSC C21189
R32, R35: 51R; R_0603_1608Metric; LCSC C23197
R33, R34, R36, R43: 20R; R_0603_1608Metric; LCSC C22950
R39, R41: 36k; R_0603_1608Metric; LCSC C23147
R40, R42: 22k; R_0603_1608Metric; LCSC C31850
R44, R46: 33k; R_0603_1608Metric; LCSC C4216
R45, R51, R52, R53, R54, R55: 100; R_0603_1608Metric; LCSC C22775
RV1, RV2, RV3, RV4: Potentiometer_Alpha_RD901F-40-00D_Single_Vertical
SW1, SW2, SW3, SW4: SW_PUSH_6mm_H8mm
TP1: TP1; TestPoint_Pad_1.5x1.5mm
TP2: TP2; TestPoint_Pad_1.5x1.5mm
TP3, TP4: SWO; TestPoint_Pad_1.5x1.5mm
U1, U3: MCP6002; SOIC-8_3.9x4.9mm_P1.27mm; LCSC C7377
U2: AMS1117-3.3; SOT-223-3_TabPin2; LCSC C6186
U4: AW20036; QFN-32-1EP_4x4mm_P0.4mm_EP2.65x2.65mm_ThermalVias; LCSC C401019
U5: W25Q128JVS; SOIC-8_5.23x5.23mm_P1.27mm; LCSC C97521
U6: 74LVC1T45W6; SOT-23-6; LCSC C7843
U7, U8, U10, U11: TL072; SOIC-8_3.9x4.9mm_P1.27mm; LCSC C6961
U13: STM32F446; LQFP-64_10x10mm_P0.5mm; LCSC C69336
Y1: 16MHz; Crystal_SMD_3225-4Pin_3.2x2.5mm; LCSC C13738

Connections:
+3V3: C8.1, C12.1, C15.1, C16.1, C19.1, C21.1, C25.1, C26.1, C27.1, C30.1, C31.1, C33.1, C34.1, C35.1, C36.1, C41.2, C42.1, C43.1, J12.4 (VDD), JP2.2 (B), R2.2, R4.2, R8.2, R10.2, R13.2, R16.2, R18.2, R39.1, R41.1, R56.2, R57.2, RV1.3, RV2.3, RV3.3, RV4.3, U1.8 (V+), U2.2 (VO), U3.8 (V+), U4.13 (VBAT), U4.23 (VBAT), U4.29 (VDD), U5.8 (VCC), U6.1 (VCCA), U13.1 (VBAT), U13.13 (VDDA), U13.19 (VDD_4), U13.32 (VIO_1), U13.48 (VDD_2), U13.64 (VIO_3)
+5V: D1.1 (K), D5.1 (K), D9.2, J1.11, J1.12, JP1.1 (A), R5.1, R6.1, U6.6 (VCCB)
+12V: C4.1, C6.1, C10.1, C13.1, C18.1, C20.1, C22.1, C24.1, J1.9, J1.10, JP1.3 (B), U7.8 (V+), U8.8 (V+), U10.8 (V+), U11.8 (V+)
/MCO: TP4.1, U13.41 (PA8)
AD0: R27.1, U8.7, U13.10 (PC2)
AD1: R26.1, U8.1, U13.11 (PC3)
AD2: R25.1, U7.7, U13.24 (PC4)
AD3: R24.1, U7.1, U13.25 (PC5)
AD4: U3.6 (-), U3.7, U13.14 (PA0-WKUP)
AD5: U3.1, U3.2 (-), U13.15 (PA1)
AD6: U1.6 (-), U1.7, U13.16 (PA2)
AD7: U1.1, U1.2 (-), U13.17 (PA3)
AO0: R37.2, U13.21 (PA5)
AO1: R38.2, U13.20 (PA4)
B0: C2.1, R1.2, U13.29 (PB10)
B1: C9.1, R3.2, U13.28 (PB2)
B2: C17.1, R7.2, U13.27 (PB1)
B3: C23.1, R9.2, U13.26 (PB0)
BOOT0: JP2.1 (A), R29.2, U13.60 (BOOT0)
DIO0: U6.3 (A), U13.23 (PA7)
DIR0: U6.5 (DIR), U13.22 (PA6)
DM: R11.2, U13.44 (PA11)
DP: R12.2, U13.45 (PA12)
FLASH_CS: U5.1 (~CS), U13.33 (PB12)
FLASH_MISO: U5.2 (DO(IO1)), U13.35 (PB14)
FLASH_MOSI: U5.5 (DI(IO0)), U13.36 (PB15)
FLASH_SCK: U5.6 (CLK), U13.34 (PB13)
GND: C1.2, C2.2, C3.2, C4.2, C5.1, C6.2, C7.1, C8.2, C9.2, C10.2, C11.1, C12.2, C13.2, C14.1, C15.2, C16.2, C17.2, C19.2, C21.2, C23.2, C25.2, C26.2, C27.2, C28.2, C29.2, C30.2, C31.2, C32.2, C33.2, C34.2, C35.2, C36.2, C37.2, C40.1, C41.1, C42.2, C43.2, D3.1 (K), D9.1, J1.3, J1.4, J2.6, J7.S, J11.A1 (GND), J11.A12 (GND), J11.B1 (GND), J11.B12 (GND), J11.S1 (SHIELD), J12.6 (VSS), J12.11 (SHIELD), JP3.1 (A), R14.2, R15.2, R29.1, R30.2, R31.2, RV1.1, RV2.1, RV3.1, RV4.1, SW1.1, SW2.1, SW3.1, SW4.1, U1.4 (V-), U2.1 (GND), U3.4 (V-), U4.24 (CLKIO), U4.25 (AD), U4.28 (GND), U5.4 (GND), U6.2 (GND), U13.18 (VSS_4), U13.63 (VSS_3)
GNDA: D6.1 (K), D8.1 (K), D15.1 (K), D17.1 (K), J3.S, J3.TN, J4.S, J4.TN, J5.S, J5.TN, J6.S, J6.TN, J8.S, J9.S, R17.1, R19.1, R40.2, R42.2, U10.5 (+), U11.5 (+), U13.12 (VSSA)
GPINT: U4.31 (INTN), U13.61 (PB8)
HWEN: U4.32 (HWEN), U13.62 (PB9)
LED_B1: D10.4 (BK), D11.4 (BK), D12.4 (BK), R34.1
LED_B2: D13.4 (BK), R43.1
LED_C1: D10.2 (A), D13.2 (A), U4.22 (C1)
LED_C2: D11.2 (A), U4.21 (C2)
LED_C3: D12.2 (A), U4.20 (C3)
LED_G1: D10.3 (GK), D11.3 (GK), D12.3 (GK), R33.1
LED_G2: D13.3 (GK), R36.1
LED_R1: D10.1 (RK), D11.1 (RK), D12.1 (RK), R32.1
LED_R2: D13.1 (RK), R35.1
NRST: C32.1, JP3.2 (B), R13.1, U13.7 (NRST)
unnamed: C1.1, C3.1, JP1.2 (C), U2.3 (VI)
unnamed: C28.1, U13.5 (OSC_IN), Y1.1
unnamed: C29.1, U13.6 (OSC_OUT), Y1.2
unnamed: C37.1, U13.30 (PB11)
unnamed: C38.1, R47.1, R49.2, U10.6 (-)
unnamed: C38.2, R49.1, R54.2, U10.7
unnamed: C39.1, R48.1, R50.2, U11.6 (-)
unnamed: C39.2, R50.1, R53.2, U11.7
unnamed: C40.2, U4.30 (CBP)
unnamed: D1.2 (A), J2.1
unnamed: D2.1 (K), R5.2
unnamed: D2.2 (A), J1.5
unnamed: D3.2 (A), R6.2
unnamed: D4.1 (K), R20.2, R45.1
unnamed: D4.2 (A), D6.2 (A)
unnamed: D7.1 (K), R21.2, R51.1
unnamed: D7.2 (A), D8.2 (A)
unnamed: D9.3, R28.2, U6.4 (B)
unnamed: D14.1 (K), R22.2, R52.1
unnamed: D14.2 (A), D15.2 (A)
unnamed: D16.1 (K), R23.2, R55.1
unnamed: D16.2 (A), D17.2 (A)
unnamed: J3.T, R45.2
unnamed: J4.T, R51.2
unnamed: J5.T, R52.2
unnamed: J6.T, R55.2
unnamed: J7.T, R28.1
unnamed: J8.T, R53.1
unnamed: J9.T, R54.1
unnamed: J11.A5 (CC1), R15.1
unnamed: J11.A6 (D+), J11.B6 (D+), R12.1
unnamed: J11.A7 (D-), J11.B7 (D-), R11.1
unnamed: J11.B5 (CC2), R14.1
unnamed: R1.1, R2.1, SW1.2
unnamed: R3.1, R4.1, SW2.2
unnamed: R7.1, R8.1, SW3.2
unnamed: R9.1, R10.1, SW4.2
unnamed: R16.1, R17.2, U7.3 (+), U7.5 (+)
unnamed: R18.1, R19.2, U8.3 (+), U8.5 (+)
unnamed: R20.1, R24.2, U7.2 (-)
unnamed: R21.1, R25.2, U7.6 (-)
unnamed: R22.1, R26.2, U8.2 (-)
unnamed: R23.1, R27.2, U8.6 (-)
unnamed: R30.1, U13.47 (VSS_2)
unnamed: R31.1, U13.31 (VSS_1)
unnamed: R32.2, U4.1 (R1)
unnamed: R33.2, U4.2 (R2)
unnamed: R34.2, U4.3 (R3)
unnamed: R35.2, U4.4 (R4)
unnamed: R36.2, U4.5 (R5)
unnamed: R37.1, R44.2, U10.2 (-)
unnamed: R38.1, R46.2, U11.2 (-)
unnamed: R39.2, R40.1, U10.3 (+)
unnamed: R41.2, R42.1, U11.3 (+)
unnamed: R43.2, U4.6 (R6)
unnamed: R44.1, R47.2, U10.1
unnamed: R46.1, R48.2, U11.1
unnamed: RV1.2, U1.3 (+)
unnamed: RV2.2, U1.5 (+)
unnamed: RV3.2, U3.3 (+)
unnamed: RV4.2, U3.5 (+)
SCL: R56.1, U4.27 (SCL), U13.58 (PB6)
SDA: R57.1, U4.26 (SDA), U13.59 (PB7)
SD_CLK: J12.5 (CLK), U13.53 (PC12)
SD_CMD: J12.3 (CMD), U13.54 (PD2)
SD_D0: J12.7 (DAT0), U13.39 (PC8)
SD_D1: J12.8 (DAT1), U13.40 (PC9)
SD_D2: J12.1 (DAT2), U13.51 (PC10)
SD_D3: J12.2 (DAT3/CD), U13.52 (PC11)
SD_DET: J12.9 (DET_B), J12.10 (DET_A), U13.38 (PC7)
SWCLK: J2.4, U13.49 (PA14)
SWDIO: J2.5, U13.46 (PA13)
TP1: TP1.1, U13.55 (PB3)
TP2: TP2.1, U13.56 (PB4)
TP3: TP3.1, U13.57 (PB5)
USART1_RX: J2.2, U13.43 (PA10)
USART1_TX: J2.3, U13.42 (PA9)
VBUS: D5.2 (A), J11.A4 (VBUS), J11.A9 (VBUS), J11.B4 (VBUS), J11.B9 (VBUS)
~FLASH_HOLD: U5.7 (IO3), U13.9 (PC1)
~FLASH_WP: U5.3 (IO2), U13.8 (PC0)

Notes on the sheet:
Designed for CH32V307, but STM32F405/STM32F407, STM32F446 & STM32F730 should be possible to use, although some pins (pin 25-31) are on different locations, such as PC5 doesn't exist and PB0, PB1, PB2, PB10, PB11 shifted one pin down.
At input
PB0
VCAP_1
PB10
NOTE!!
PB11
CH32V307 - No need to mount STM32F405 - No need to mount STM32F446 - Required (VCAP_1) STM32F730 - Required (VCAP_1)
CH32V307 - Mount 0R STM32F405 - Mount 4.7uF (VCAP_n) STM32F446 - Mount 0R STM32F730 - Mount 0R
PB1
Over opamp supply
PB2

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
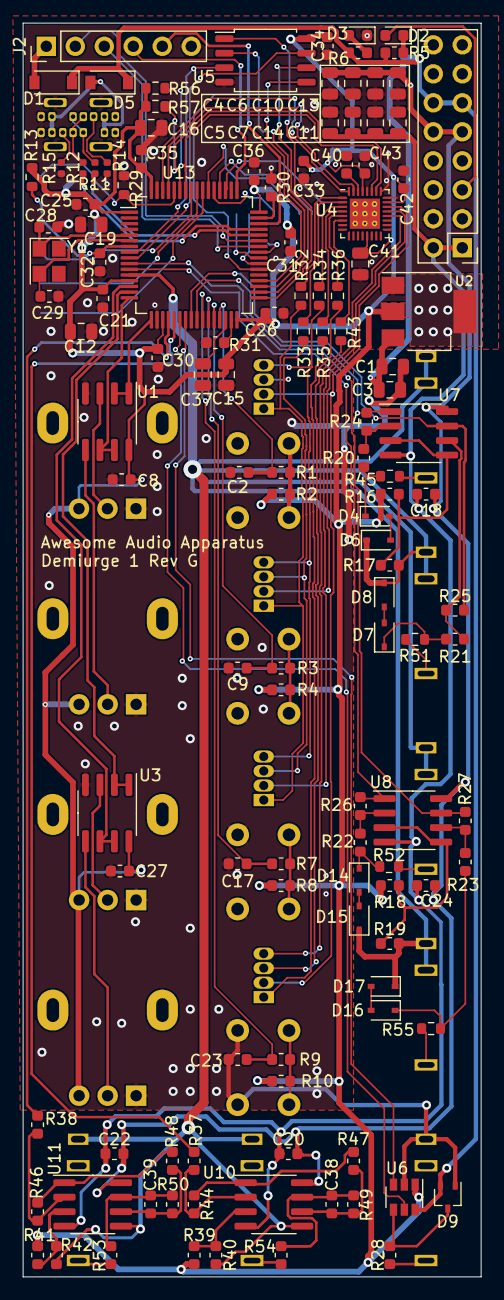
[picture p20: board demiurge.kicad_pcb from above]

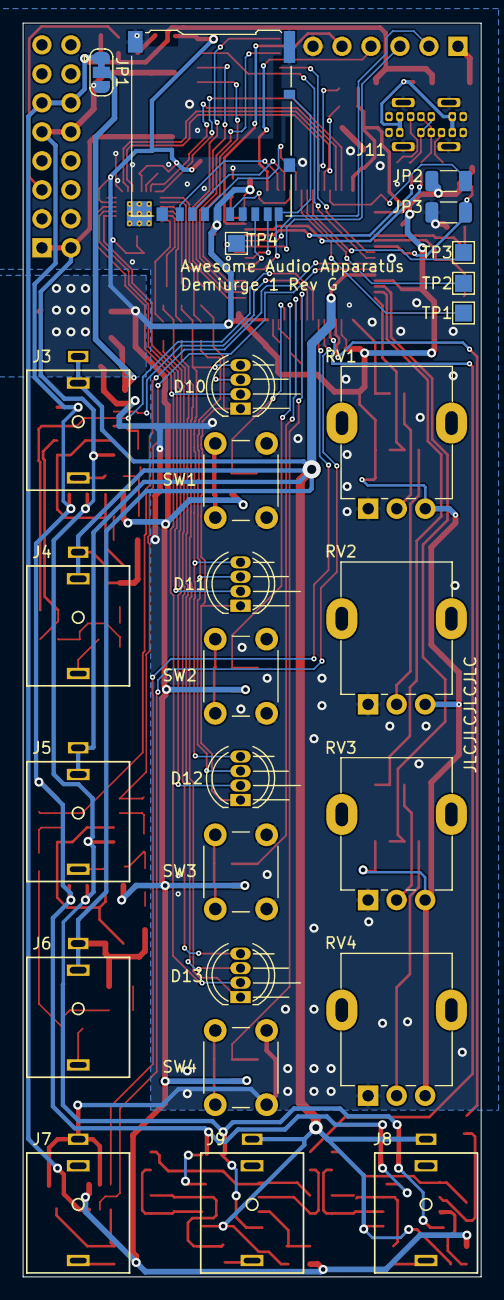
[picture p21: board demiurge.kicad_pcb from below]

Board: 2 copper layers, 40.1 x 109.9 mm, 155 parts (28 on the bottom side), 122 nets.

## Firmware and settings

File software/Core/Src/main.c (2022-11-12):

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
/* Includes ------------------------------------------------------------------*/
#include "main.h"

/* USER CODE BEGIN Includes */
#include "demiurge-hardware.h"
#include  <errno.h>
#include  <sys/unistd.h> // STDOUT_FILENO, STDERR_FILENO
/* USER CODE END Includes */

ADC_HandleTypeDef hadc1;
DMA_HandleTypeDef hdma_adc1;

DAC_HandleTypeDef hdac;

I2C_HandleTypeDef hi2c1;
DMA_HandleTypeDef hdma_i2c1_tx;

SPI_HandleTypeDef hspi2;

TIM_HandleTypeDef htim3;

UART_HandleTypeDef huart1;

void SystemClock_Config(void);
static void MX_GPIO_Init(void);
static void MX_DMA_Init(void);
static void MX_ADC1_Init(void);
static void MX_DAC_Init(void);
static void MX_TIM3_Init(void);
static void MX_I2C1_Init(void);
static void MX_SPI2_Init(void);
static void MX_USART1_UART_Init(void);
/**
  * @brief  The application entry point.
  * @retval int
  */
int main(void)
{
  /* MCU Configuration--------------------------------------------------------*/

  /* Reset of all peripherals, Initializes the Flash interface and the Systick. */
  HAL_Init();

  /* Configure the system clock */
  SystemClock_Config();

  /* Initialize all configured peripherals */
  MX_GPIO_Init();
  MX_DMA_Init();
  MX_ADC1_Init();
  MX_DAC_Init();
  MX_TIM3_Init();
  MX_I2C1_Init();
  MX_SPI2_Init();
  MX_USART1_UART_Init();
  /* USER CODE BEGIN 2 */
  MX_User_Init();
  /* USER CODE END 2 */

  /* Infinite loop */
  /* USER CODE BEGIN WHILE */
  while (1)
  {
      MX_User_Process();
    /* USER CODE END WHILE */

    /* USER CODE BEGIN 3 */
  }
  /* USER CODE END 3 */
}

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
/* USER CODE BEGIN 4 */
int _write(int file, char *data, int len)
{
    if ((file != STDOUT_FILENO) && (file != STDERR_FILENO))
    {
        errno = EBADF;
        return -1;
    }

    // arbitrary timeout 1000
    HAL_StatusTypeDef status =
            HAL_UART_Transmit(&huart1, (uint8_t*)data, len, 1000);

    // return # of bytes written - as best we can tell
    return (status == HAL_OK ? len : 0);
}
/* USER CODE END 4 */
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


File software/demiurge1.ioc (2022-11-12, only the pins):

Mcu.UserName=STM32F446RETx
PA0-WKUP.Signal=ADCx_IN0
PA1.Signal=ADCx_IN1
PA10.Signal=USART1_RX
PA11.Signal=USB_OTG_FS_DM
PA12.Signal=USB_OTG_FS_DP
PA13.Signal=SYS_JTMS-SWDIO
PA14.Signal=SYS_JTCK-SWCLK
PA2.Signal=ADCx_IN2
PA3.Signal=ADCx_IN3
PA4.Signal=COMP_DAC1_group
PA5.Signal=COMP_DAC2_group
PA6.Signal=GPIO_Output
PA7.Signal=GPIO_Input
PA8.Signal=RCC_MCO_1
PA9.Signal=USART1_TX
PB0.Signal=GPIO_Input
PB1.Signal=GPIO_Input
PB10.Signal=GPIO_Input
PB12.Signal=SPI2_NSS
PB13.Signal=SPI2_SCK
PB14.Signal=SPI2_MISO
PB15.Signal=SPI2_MOSI
PB2.Signal=GPIO_Input
PB3.Signal=GPIO_Output
PB4.Signal=GPIO_Output
PB5.Signal=GPIO_Output
PB6.Signal=I2C1_SCL
PB7.Signal=I2C1_SDA
PB8.Signal=GPIO_Input
PB9.Signal=GPIO_Output
PC0.Signal=GPIO_Output
PC1.Signal=GPIO_Output
PC10.Signal=SDIO_D2
PC11.Signal=SDIO_D3
PC12.Signal=SDIO_CK
PC2.Signal=ADCx_IN12
PC3.Signal=ADCx_IN13
PC4.Signal=ADCx_IN14
PC5.Signal=ADCx_IN15
PC7.Signal=GPIO_Input
PC8.Signal=SDIO_D0
PC9.Signal=SDIO_D1
PD2.Signal=SDIO_CMD
PH0-OSC_IN.Signal=RCC_OSC_IN
PH1-OSC_OUT.Signal=RCC_OSC_OUT

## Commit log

2022-05-20 Adding HW design.
    [analog-in.kicad_sch, analog-out.kicad_sch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]
2022-05-20 Added USB1/USB2 labels. What should we do with 2 USB ports?
    [demiurge.kicad_sch]
2022-06-25 First cut of the software. Not changed to RISC-V yet.
    [aaa-dev-board.cfg, analog-out.kicad_sch, demiurge.kicad_pcb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]
2022-06-26 First running on the generic devkit.
    [aaa-dev-board.cfg, stm32f4discovery.cfg]
2022-07-05 adc working
2022-07-09 Fixed driver for ADC conversion. Worked on octave_per_volt
2022-07-12 Trying to get Flash working, but there are something causing time-dependency and the function is not working yet.
    [main.c]
2022-08-04 Rev E updated to Rev F (WIP)
    [analog-in.kicad_sch, analog-out.kicad_sch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]
2022-08-04 AW9523 is discontinued @ LCSC. Changing to AW20036, capable of up to 12 RGB LEDs.
    [demiurge.kicad_pcb, demiurge.kicad_sch]
2022-08-05 Massive restructuring to start supporting additional boards and MCUs.
2022-08-06 Rearrange the hardware part as well, to allow more boards, and put submodule link to libraries.
    [demiurge-B_Cu.gbr, demiurge-B_Mask.gbr, demiurge-B_Paste.gbr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]
2022-08-06 Defined 3 build targets. 'startup' seems to be a reserved word in MOunRiver or something, so renaming the startup folder with the initial assembler.
2022-08-06 Finalizing reshuffle of hardware.
    [demiurge-B_Cu.gbr, demiurge-B_Mask.gbr, demiurge-B_Paste.gbr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]
2022-08-09 Adding testpad for MCO pin, for instance to check clock speeds.
    [demiurge.kicad_pcb, demiurge.kicad_sch]
2022-08-09 Fixed adsr, and the speed is back to 144MHz.
    [main.c]
2022-08-10 Various fixes and got to the VCO+Envelope+VCA demo.
    [main.c]
2022-08-11 RevF order made at jlcpcb.
    [demiurge-B_Cu.gbr, demiurge-B_Mask.gbr, demiurge-B_Paste.gbr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]
2022-08-11 Adding front panel template
    [demiurge-panel_template-B_Cu.gbr, demiurge-panel_template-B_Mask.gbr, demiurge-panel_template-B_Paste.gbr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]
2022-08-11 Filled background in drawings.
    [demiurge-panel_template.kicad_pcb]
2022-08-12 Detailing the frontpanel template.
    [demiurge-panel_template-B_Cu.gbr, demiurge-panel_template-B_Mask.gbr, demiurge-panel_template-B_Paste.gbr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]
2022-08-14 Added schematics plot
2022-08-16 Nail down the octave/volt function
2022-08-16 Removed inverted output on the sample Envelope. Not sure if the 'output buffer' is disabled by default or not. Make it explicit.
    [main.c]
2022-08-22 Work on the build system and not be dependent on MounRiver.
    [demiurge-panel_template.kicad_pcb]
2022-09-03 Forgot I2C resistors. Grrr...
    [demiurge.kicad_pcb, demiurge.kicad_sch]
2022-09-03 Adding comment that STM32F446 can also be used.
    [demiurge.kicad_sch]
2022-09-03 adding photos of the board
2022-10-05 LEDs working
2022-10-05 RevG using STM32F446.
    [demiurge-1-RevG_bom.csv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]
2022-11-02 Halfway point to get STM32 dev environment and STM32CubeMX Pack publishing working.
    [demiurge-panel_adsr-B_Cu.gbr, demiurge-panel_adsr-B_Mask.gbr, demiurge-panel_adsr-B_Paste.gbr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]
2022-11-03 Tuning the build/IDE system for development. Added TIM3 interrupt handler in .ioc file.
    [demiurge1.cfg]
2022-11-04 ADC and DAC working.
2022-11-05 PB9 was not an Output
    [demiurge.kicad_pcb]
2022-11-08 Buttons and LEDs are now working.
2022-11-12 Get the ADC channels in the right spots.
2023-02-19 wrong file names on RevG photos.
    [demiurge.kicad_pcb, demiurge.kicad_sch]

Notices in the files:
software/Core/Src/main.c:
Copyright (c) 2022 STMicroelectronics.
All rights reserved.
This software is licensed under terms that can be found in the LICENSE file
